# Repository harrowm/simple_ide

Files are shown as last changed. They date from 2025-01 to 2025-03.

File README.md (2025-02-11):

# simple_ide
A very simple IDE interface for the rosco_m68k using two atf22v10 GAL chips

With a lot of thanks to the following projects:  
https://github.com/crmaykish/mackerel-68k/tree/master  
https://github.com/markrvmurray/rosco-ide-ata  

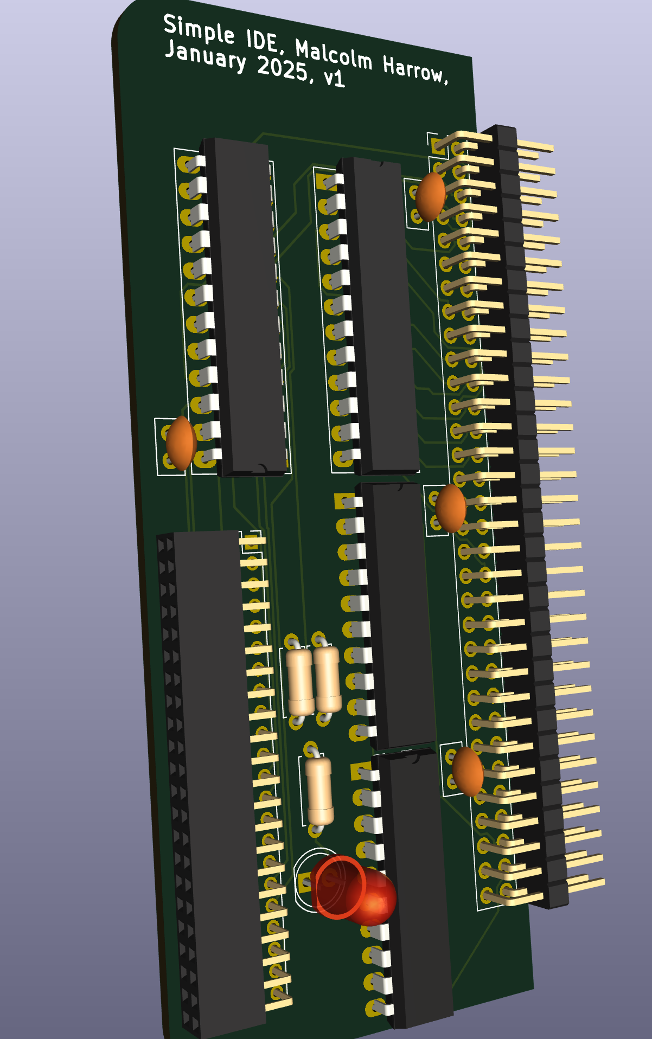
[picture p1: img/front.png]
3d model of board - front

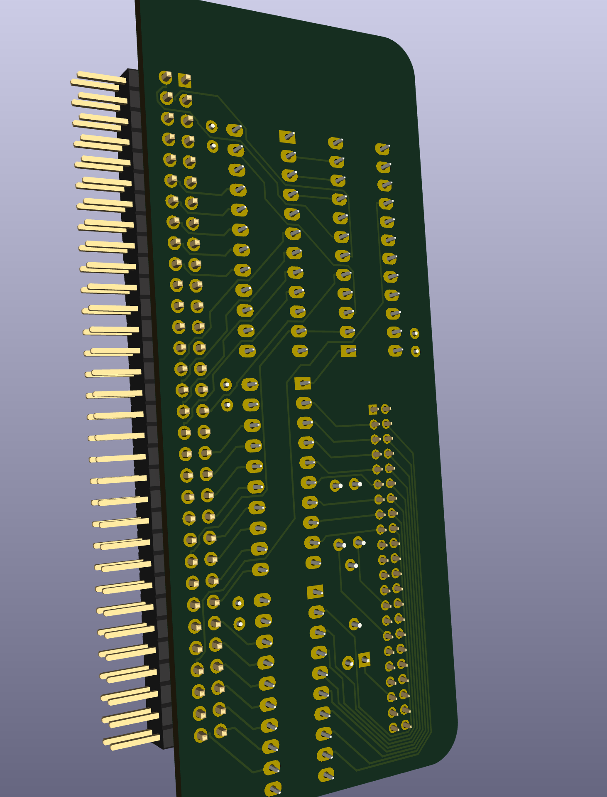
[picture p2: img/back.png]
3d model of board - back


Status as at 11th Feb 2025: This board is not yet working .. the first version has a timing issue on reads.  Working to fix this ..  

To build the rosco firmware with ATA enabled:

    cd
    git clone https://github.com/rosco-m68k/rosco_m68k.git
    cd rosco_m68k/code/firmware/rosco_m68k_firmware
    git submodule update --init --recursive
    WITH_ATA=true ATA_DEBUG=true make clean all

    # copy the ROM images to a SD Card named ROSCO32 on a Mac
    cp rosco_m68k.rom /Volumes/ROSCO32 

.. mmm, had to edit the Makefiule to disable the creation of the rom filesystem as adding in the drivers means the default filesystem doesnt fit into the roms :sob:  
.. double mmm, the generated rom file had an odd size that the in system rom programming utility rejects as invalid.  Patch the file to an even size with the command:  
    
    truncate -s%2 rosco_m68k.rom

    # copy the update flash utility and rom images to a SD card named ROSCO32 on a Mac
    cd
    cd rosco_m68k/code/software
    cp updateflash/updateflash.bin /Volumes/ROSCO32

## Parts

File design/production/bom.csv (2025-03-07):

Designator | Footprint | Quantity | Value | LCSC Part #
BUS1 | PinHeader_2x32_P2.54mm_Vertical | 1 | Conn_02x32_Odd_Even
C1, C2, C3, C4 | C_Disc_D5.0mm_W2.5mm_P2.50mm | 4 | 100nF | C49678
IC1, IC2 | DIP-24_W7.62mm_Socket_LongPads | 2 | ATF22V10C-15PU
IC3, IC4 | DIP-20_W7.62mm_LongPads | 2 | 74245
J1, J3, J4, J5 | PinHeader_1x11_P2.54mm_Vertical | 4 | Conn_01x11_Pin
J2 | PinSocket_2x22_P2.00mm_Vertical | 1 | Conn_02x22_Odd_Even

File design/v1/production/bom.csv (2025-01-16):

Designator | Footprint | Quantity | Value | LCSC Part #
BUS1 | PinHeader_2x32_P2.54mm_Vertical | 1 | Conn_02x32_Odd_Even
C1, C2, C3, C4 | C_Disc_D5.0mm_W2.5mm_P2.50mm | 4 | 100nF | C49678
D2 | LED_D5.0mm | 1 | LED
IC1, IC2 | DIP-24_W7.62mm_Socket_LongPads | 2 | ATF22V10C-15PU
IC3, IC4 | DIP-20_W7.62mm_LongPads | 2 | 74ACT245
J2 | PinSocket_2x22_P2.00mm_Vertical | 1 | Conn_02x22_Odd_Even
R1 | R_Axial_DIN0207_L6.3mm_D2.5mm_P7.62mm_Horizontal | 1 | 1K | C17513
R2, R3 | R_Axial_DIN0207_L6.3mm_D2.5mm_P7.62mm_Horizontal | 2 | 4K7

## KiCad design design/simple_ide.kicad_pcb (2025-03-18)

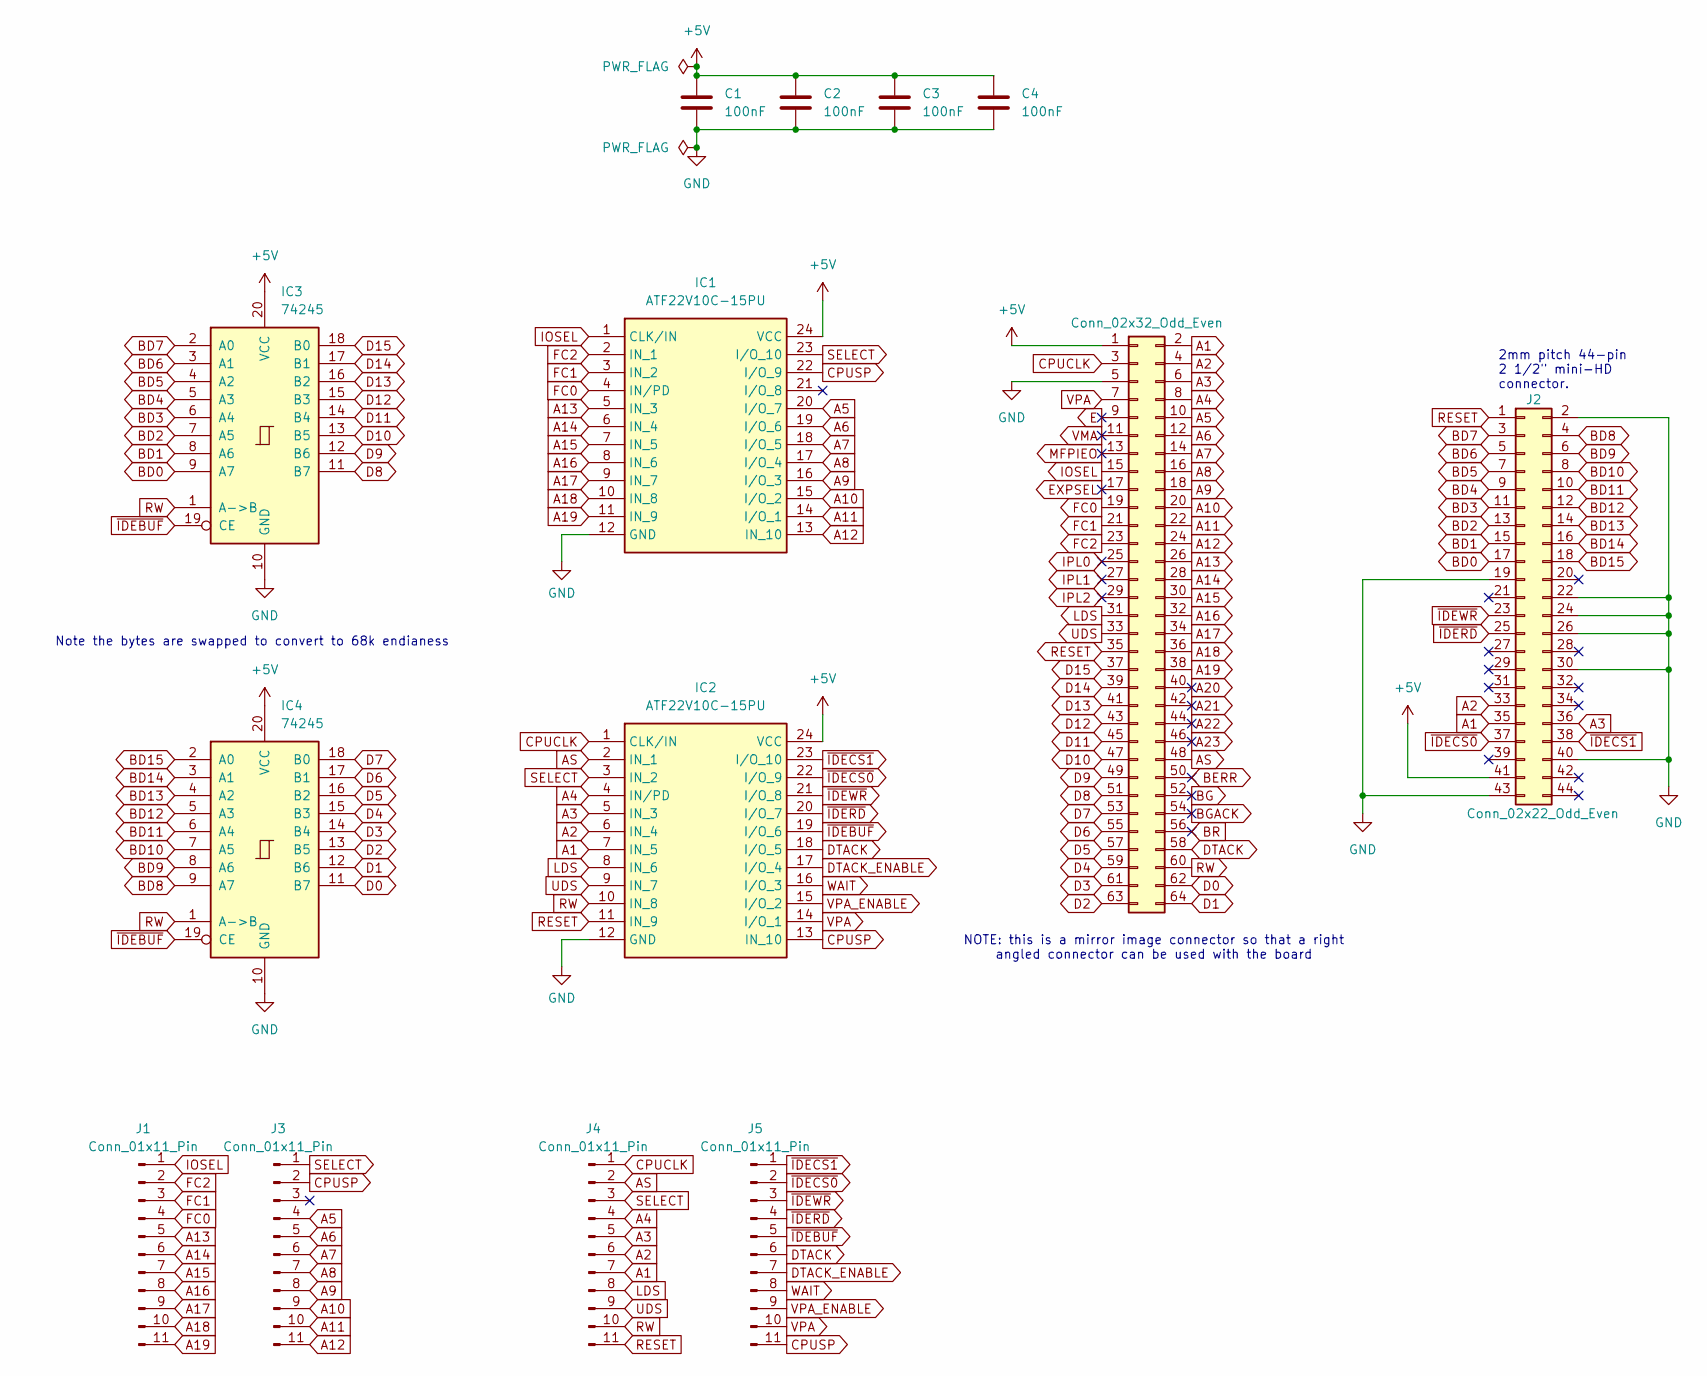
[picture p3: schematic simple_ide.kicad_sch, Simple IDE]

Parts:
BUS1: Conn_02x32_Odd_Even; PinHeader_2x32_P2.54mm_Vertical
C1, C2, C3, C4: 100nF; C_Disc_D5.0mm_W2.5mm_P2.50mm; JLC 0805
IC1, IC2: ATF22V10C-15PU; DIP-24_W7.62mm_Socket_LongPads; Mouser Part Number 556-AF22V10C15PU
IC3, IC4: 74245; DIP-20_W7.62mm_LongPads
J1, J3, J4, J5: Conn_01x11_Pin; PinHeader_1x11_P2.54mm_Vertical
J2: Conn_02x22_Odd_Even; PinSocket_2x22_P2.00mm_Vertical

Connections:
+5V: BUS1.1, C1.1, C2.1, C3.1, C4.1, IC1.24 (VCC), IC2.24 (VCC), IC3.20 (VCC), IC4.20 (VCC), J2.41
A1: BUS1.2, IC2.7 (IN_5), J2.35, J4.7
A2: BUS1.4, IC2.6 (IN_4), J2.33, J4.6
A3: BUS1.6, IC2.5 (IN_3), J2.36, J4.5
A4: BUS1.8, IC2.4 (IN/PD), J4.4
A5: BUS1.10, IC1.20 (I/O_7), J3.4
A6: BUS1.12, IC1.19 (I/O_6), J3.5
A7: BUS1.14, IC1.18 (I/O_5), J3.6
A8: BUS1.16, IC1.17 (I/O_4), J3.7
A9: BUS1.18, IC1.16 (I/O_3), J3.8
A10: BUS1.20, IC1.15 (I/O_2), J3.9
A11: BUS1.22, IC1.14 (I/O_1), J3.10
A12: BUS1.24, IC1.13 (IN_10), J3.11
A13: BUS1.26, IC1.5 (IN_3), J1.5
A14: BUS1.28, IC1.6 (IN_4), J1.6
A15: BUS1.30, IC1.7 (IN_5), J1.7
A16: BUS1.32, IC1.8 (IN_6), J1.8
A17: BUS1.34, IC1.9 (IN_7), J1.9
A18: BUS1.36, IC1.10 (IN_8), J1.10
A19: BUS1.38, IC1.11 (IN_9), J1.11
A20: BUS1.40
A21: BUS1.42
A22: BUS1.44
A23: BUS1.46
AS: BUS1.48, IC2.2 (IN_1), J4.2
BD0: IC3.9 (A7), J2.17
BD1: IC3.8 (A6), J2.15
BD2: IC3.7 (A5), J2.13
BD3: IC3.6 (A4), J2.11
BD4: IC3.5 (A3), J2.9
BD5: IC3.4 (A2), J2.7
BD6: IC3.3 (A1), J2.5
BD7: IC3.2 (A0), J2.3
BD8: IC4.9 (A7), J2.4
BD9: IC4.8 (A6), J2.6
BD10: IC4.7 (A5), J2.8
BD11: IC4.6 (A4), J2.10
BD12: IC4.5 (A3), J2.12
BD13: IC4.4 (A2), J2.14
BD14: IC4.3 (A1), J2.16
BD15: IC4.2 (A0), J2.18
BERR: BUS1.50
BG: BUS1.52
BGACK: BUS1.54
BR: BUS1.56
CPUCLK: BUS1.3, IC2.1 (CLK/IN), J4.1
CPUSP: IC1.22 (I/O_9), IC2.13 (IN_10), J3.2, J5.11
D0: BUS1.62, IC4.11 (B7)
D1: BUS1.64, IC4.12 (B6)
D2: BUS1.63, IC4.13 (B5)
D3: BUS1.61, IC4.14 (B4)
D4: BUS1.59, IC4.15 (B3)
D5: BUS1.57, IC4.16 (B2)
D6: BUS1.55, IC4.17 (B1)
D7: BUS1.53, IC4.18 (B0)
D8: BUS1.51, IC3.11 (B7)
D9: BUS1.49, IC3.12 (B6)
D10: BUS1.47, IC3.13 (B5)
D11: BUS1.45, IC3.14 (B4)
D12: BUS1.43, IC3.15 (B3)
D13: BUS1.41, IC3.16 (B2)
D14: BUS1.39, IC3.17 (B1)
D15: BUS1.37, IC3.18 (B0)
DTACK: BUS1.58, IC2.18 (I/O_5), J5.6
DTACK_ENABLE: IC2.17 (I/O_4), J5.7
E: BUS1.9
EXPSEL: BUS1.17
FC0: BUS1.19, IC1.4 (IN/PD), J1.4
FC1: BUS1.21, IC1.3 (IN_2), J1.3
FC2: BUS1.23, IC1.2 (IN_1), J1.2
GND: BUS1.5, C1.2, C2.2, C3.2, C4.2, IC1.12 (GND), IC2.12 (GND), IC3.10 (GND), IC4.10 (GND), J2.2, J2.19, J2.22, J2.24, J2.26, J2.30, J2.40, J2.43
IOSEL: BUS1.15, IC1.1 (CLK/IN), J1.1
IPL0: BUS1.25
IPL1: BUS1.27
IPL2: BUS1.29
LDS: BUS1.31, IC2.8 (IN_6), J4.8
MFPIEO: BUS1.13
RESET: BUS1.35, IC2.11 (IN_9), J2.1, J4.11
RW: BUS1.60, IC2.10 (IN_8), IC3.1 (A->B), IC4.1 (A->B), J4.10
SELECT: IC1.23 (I/O_10), IC2.3 (IN_2), J3.1, J4.3
UDS: BUS1.33, IC2.9 (IN_7), J4.9
VMA: BUS1.11
VPA: BUS1.7, IC2.14 (I/O_1), J5.10
VPA_ENABLE: IC2.15 (I/O_2), J5.9
WAIT: IC2.16 (I/O_3), J5.8
~IDEBUF: IC2.19 (I/O_6), IC3.19 (CE), IC4.19 (CE), J5.5
~IDECS0: IC2.22 (I/O_9), J2.37, J5.2
~IDECS1: IC2.23 (I/O_10), J2.38, J5.1
~IDERD: IC2.20 (I/O_7), J2.25, J5.4
~IDEWR: IC2.21 (I/O_8), J2.23, J5.3

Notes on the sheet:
2mm pitch 44-pin 2 1/2" mini-HD connector.
NOTE: this is a mirror image connector so that a right angled connector can be used with the board
Note the bytes are swapped to convert to 68k endianess

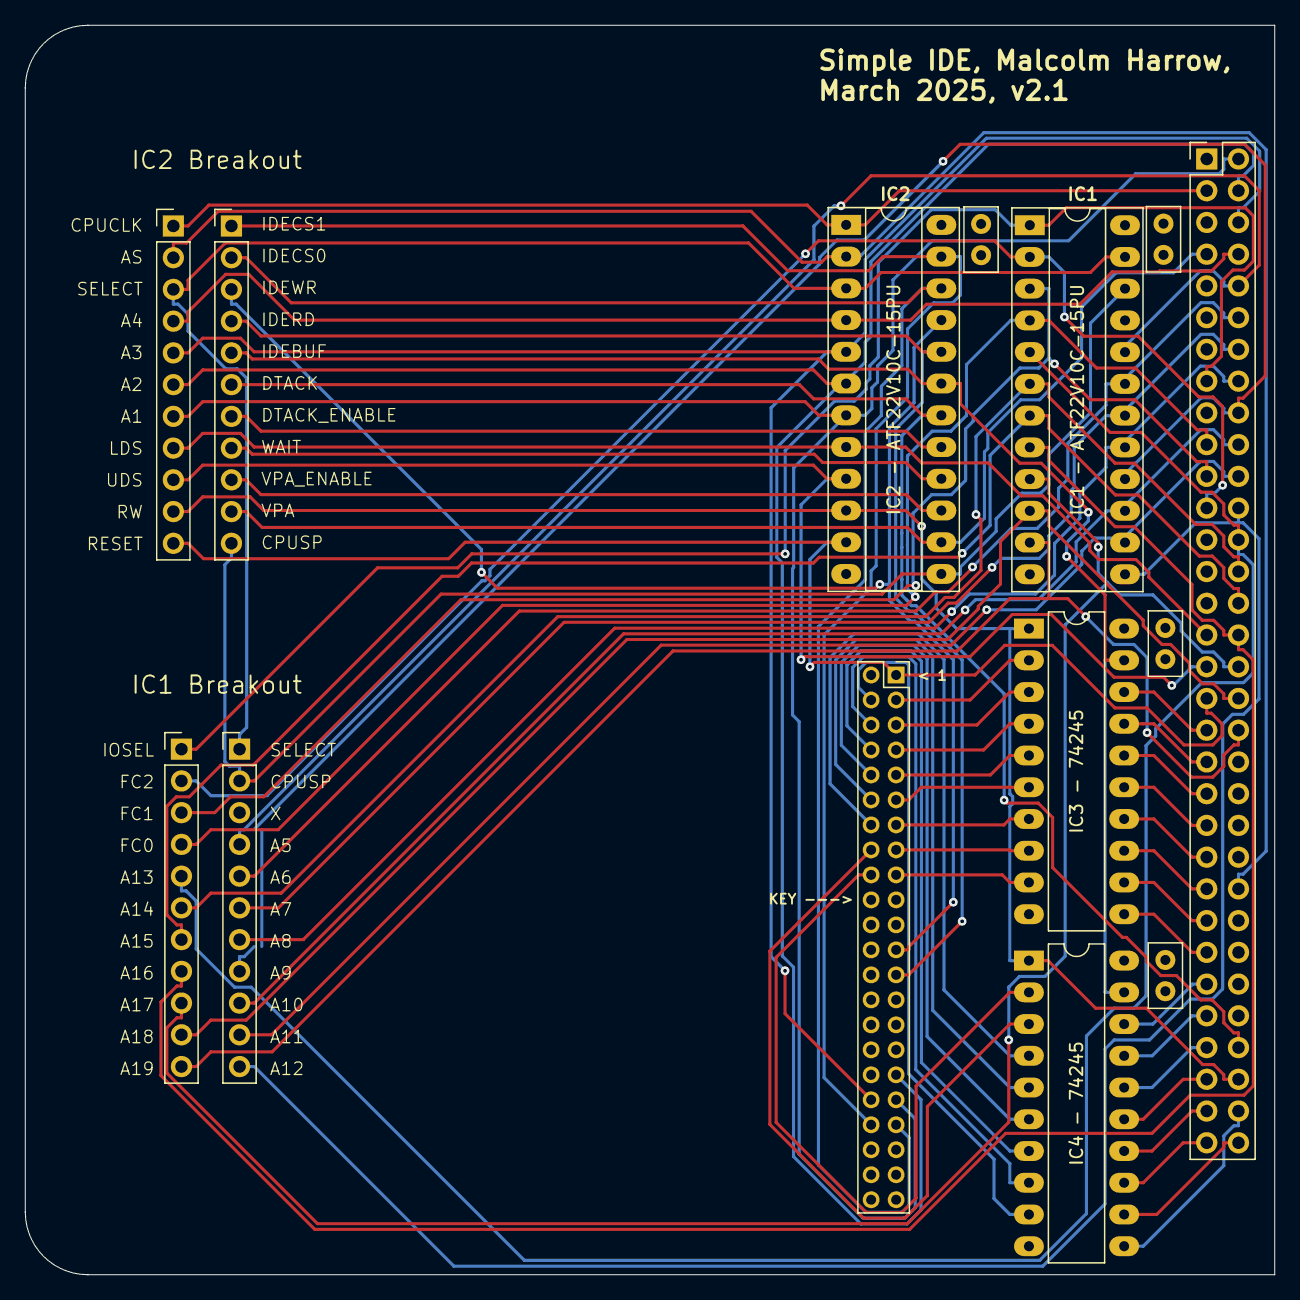
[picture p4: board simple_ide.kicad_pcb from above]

Board: 4 copper layers, 100.0 x 100.0 mm, 14 parts (0 on the bottom side), 75 nets.

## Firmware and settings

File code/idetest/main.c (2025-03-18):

// Test harness for simple IDE
// Malcolm Harrow, November 2024
//
// MIT license
//
// Derived from the Mackerel IDE example:
//   https://github.com/crmaykish/mackerel-68k/blob/master/firmware/hello.c

#include "ide.h"
#include <stdio.h>
#include <string.h>

void hexdump(uint8_t *buf, size_t len)
{
    for (size_t i = 0; i < len; i += 16)
    {
        printf("%08x  ", i);
        for (size_t j = 0; j < 16; j++)
        {
            if (i + j < len)
                printf("%02x ", buf[i + j]);
            else
                printf("   ");
        }
        printf(" ");
        for (size_t j = 0; j < 16; j++)
        {
            if (i + j < len)
            {
                uint8_t c = buf[i + j];
                if (c >= 32 && c <= 126)
                    printf("%c", c);
                else
                    printf(".");
            }
        }
        printf("\n");
    }
}

int main()
{
    uint16_t buf[256] = {0};

    printf("IDE Demo, interface mapped at %08X\n", IDE_BASE);

    if (!IDE_reset()) {
        return(1);
    }

    
    printf("Get drive info\n");
    IDE_device_info(buf);
    hexdump((uint8_t *)buf, 512);

    printf("Read sector 1\n");
    IDE_read_sector(buf, 1);
    hexdump((uint8_t *)buf, 512);

    printf("Read sector 2\n");
    IDE_read_sector(buf, 2);
    hexdump((uint8_t *)buf, 512);

    printf("Done\n");
    return 0;
}

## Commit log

2024-11-04 get pld working
    [bom.csv, designators.csv, positions.csv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]
2024-11-04 Get pld code working
    [bom.csv, designators.csv, positions.csv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]
2025-01-14 Added KiCad design
    [simple_ide.kicad_pcb, simple_ide.kicad_sch]
2025-01-15 Recheck WinCUPL against design
    [simple_ide.kicad_pcb, simple_ide.kicad_sch]
2025-01-16 Compile Wincuple and reroute pins to ensure outputs on output pins
    [simple_ide.kicad_pcb, simple_ide.kicad_sch]
2025-01-16 Add production files
    [bom.csv, designators.csv, positions.csv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]
2025-02-04 Start work on v2
    [simple_ide.kicad_pcb, simple_ide.kicad_sch]
2025-02-10 Add in script to contriol WinCupl
    [bom.csv, designators.csv, positions.csv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]
2025-02-11 Further work on pld, tidy up readme, add images
    [simple_ide.kicad_pcb]
2025-03-07 First test of v2 production files .. seems to read a disk ok
    [bom.csv, designators.csv, positions.csv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]
2025-03-18 Save copy of firmware
    [simple_ide.kicad_pcb]

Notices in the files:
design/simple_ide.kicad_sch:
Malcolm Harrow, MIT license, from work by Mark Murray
